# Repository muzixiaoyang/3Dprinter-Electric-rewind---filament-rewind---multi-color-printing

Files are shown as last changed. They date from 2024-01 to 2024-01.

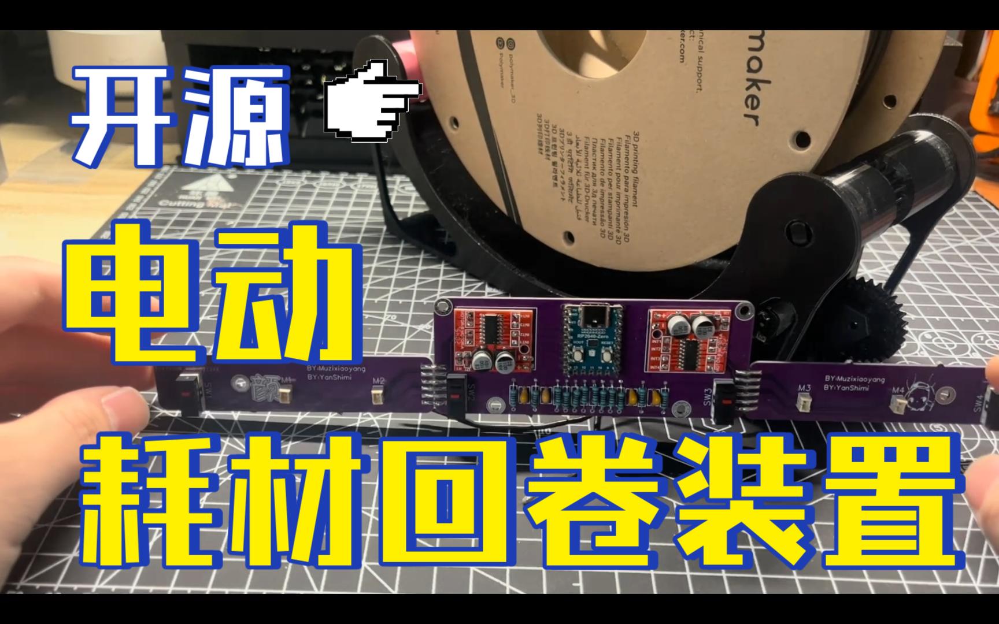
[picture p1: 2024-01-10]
封面.jpg

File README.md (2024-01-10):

# 3Dprinter-Electric-rewind---filament-rewind---multi-color-printing
【3D Printer】electric rewinf - filament rewind - multi-color printing
【3D打印机】稳定至上的电动回卷-耗材回卷-多色打印

During multi-color printing,
If you can't solve the winding in the rewind,
It will affect the next filament feeding and printing

The advantage of passive rewinding is that there is no involvement of electronic components.
However, there will be problems such as excessive resistance, complex structure, and large volume

So in the process of developing wood polychrome,
Specially designed for such as rabbit multicolor, TR multicolor, etc.,
Other types of multi-color printing are equipped with a motorized rewinding device
Advantages: cheap and quite cheap, simple structure, strong stability, long working time, long rewinding distance
Cons: Requires one or more USBs to be occupied

Thank you Yanshimi for your support and help
Thank you for the thoughts and ideas of the pending elder brother
Thanks to the group of friends Frog Brother copywriting and embellishment

在多色打印过程中，
如果不能解决回卷中缠绕，
将会影响下一次耗材的送料与打印

被动回卷的优势在于无电子元器件的参与，
但是会存在着阻力过大，结构复杂，体积较大的问题等

所以在开发木子多色的过程中，
特意为诸如兔子多色，TR多色等，
其他类别的多色打印预备了一套电动回卷装置
优势：价格便宜相当便宜，结构简单，稳定性强，工作时间长，回卷距离长
缺点：需要占用一个或多个USB

感谢Yanshimi大佬的支持与帮助
感谢群友待定老哥的思路与想法
感谢群友青蛙哥文案与修饰

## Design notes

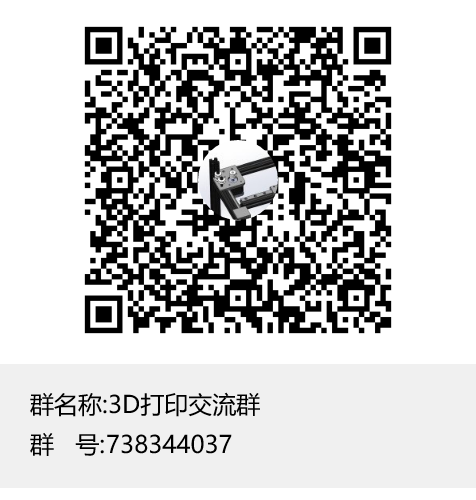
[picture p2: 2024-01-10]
【3D打印机】稳定之上的电动回卷-木子小阳/3D打印交流群群聊二维码.png

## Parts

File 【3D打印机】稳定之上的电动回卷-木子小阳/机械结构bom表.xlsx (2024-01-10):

本人仅提供材料链接，与店家并无任何利益关系 |  | 大家可以根据个人需求自行调整材料选取
B站演示链接： |  | https://www.bilibili.com/video/BV1MT4y1n7Rv/
嘉立创链接： |  | https://oshwhub.com/muzixiaoxiaoyang/dian-dong-hui-juan-mu-zi-xiao-yang
github链接： |  | https://github.com/muzixiaoyang/3Dprinter-Electric-rewind---filament-rewind---multi-color-printing
以后会出更多内容，可以关注一下不迷路
材料名称 | 材料数量 | 材料链接
608ZZ轴承 | 16 | https://item.taobao.com/item.htm?abbucket=13&id=559732852013&ns=1&skuId=3493880373151
鲍登头 | 4 | https://item.taobao.com/item.htm?id=654102804547&ns=1&abbucket=13
铜嵌入螺母【M3*4*5】 | 8 | https://detail.tmall.com/item.htm?_u=g2m84rkn86ac&id=691362839974&skuId=5085575338786
M1.6*4 | 8 | https://item.taobao.com/item.htm?id=732152088630&ns=1&abbucket=13
M3螺母 | 6 | https://item.taobao.com/item.htm?spm=a1z10.3-c-s.w4002-25176723813.11.188c504fscstHN&id=712768127528
M3*6螺丝 | 8 | https://item.taobao.com/item.htm?id=732152088630&ns=1&abbucket=13
M3*8螺丝 | 14 | https://item.taobao.com/item.htm?id=732152088630&ns=1&abbucket=13
M3*12螺丝 | 16 | https://item.taobao.com/item.htm?id=732152088630&ns=1&abbucket=13
M3*20螺丝 | 16 | https://item.taobao.com/item.htm?id=732152088630&ns=1&abbucket=13
此外不想组装或采购的话，可以直接咸鱼搜索”木子小阳“ | → | 那个卖干燥箱的就是我，我有这里有成品和套件售卖
 |  | B站：木子小小阳
 |  | QQ群：826091829

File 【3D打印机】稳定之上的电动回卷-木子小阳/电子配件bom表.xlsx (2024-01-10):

本人仅提供材料链接，与店家并无任何利益关系 |  | 大家可以根据个人需求自行调整材料选取
B站演示链接： |  | https://www.bilibili.com/video/BV1MT4y1n7Rv/
嘉立创链接： |  | https://oshwhub.com/muzixiaoxiaoyang/dian-dong-hui-juan-mu-zi-xiao-yang
github链接： |  | https://github.com/muzixiaoyang/3Dprinter-Electric-rewind---filament-rewind---multi-color-printing
以后会出更多内容，可以关注一下不迷路
材料名称 | 材料数量 | 材料链接
RP2040-Zero开发板 树莓派pico开发板 基于官方RP2040 焊排针 | 1 | https://item.taobao.com/item.htm?_u=72m84rkn8583&id=740532900376&spm=a1z09.2.0.0.2bac2e8dSXnIFg
2路直流电机驱动模块 正反转 | 2 | https://item.taobao.com/item.htm?spm=a1z09.2.0.0.2bac2e8dSXnIFg&id=576711157149&_u=72m84rkne464
金属膜电阻 1/4W 1% 五色环 10千欧 10K | 12 | https://item.taobao.com/item.htm?_u=72m84rkn68e4&id=522577576434&spm=a1z09.2.0.0.2bac2e8dSXnIFg
独石电容 0.1UF 104 100NF | 4 | https://item.taobao.com/item.htm?_u=72m84rkn4f11&id=522575085023&spm=a1z09.2.0.0.2bac2e8dSXnIFg1
1.25直针 1.25mm间距 2PIN | 4 | https://item.taobao.com/item.htm?id=528813512664&skuId=3148215795013
N20减速电机 | 4 | https://item.taobao.com/item.htm?_u=72m84rkn32a8&id=671009663139&spm=a1z09.2.0.0.7f3a2e8dZjZMkW
小型微动开关 无柄 （耗材检测款） | 4 | https://item.taobao.com/item.htm?id=607968305821&skuId=4441187151303
6MM钢珠（耗材检测款） | 4 | https://detail.tmall.com/item.htm?abbucket=13&id=620846633904&ns=1&skuId=4391174781008
此外不想组装或采购的话，可以直接咸鱼搜索”木子小阳“ | → | 那个卖干燥箱的就是我，我有这里有成品和套件售卖
 |  | B站：木子小小阳
 |  | QQ群：826091829

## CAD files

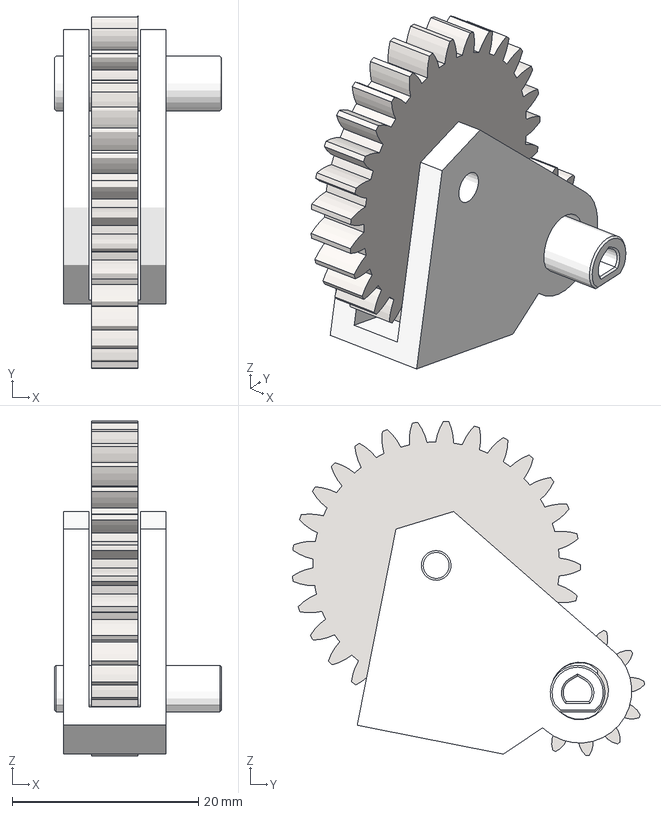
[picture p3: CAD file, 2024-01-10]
【3D打印机】稳定之上的电动回卷-木子小阳/打印件/20L款4通道电动回卷打印件-木子小阳/齿轮组4套.3mf
18.0 x 37.8 x 36.0 mm
实体1
实体2
实体3
实体4

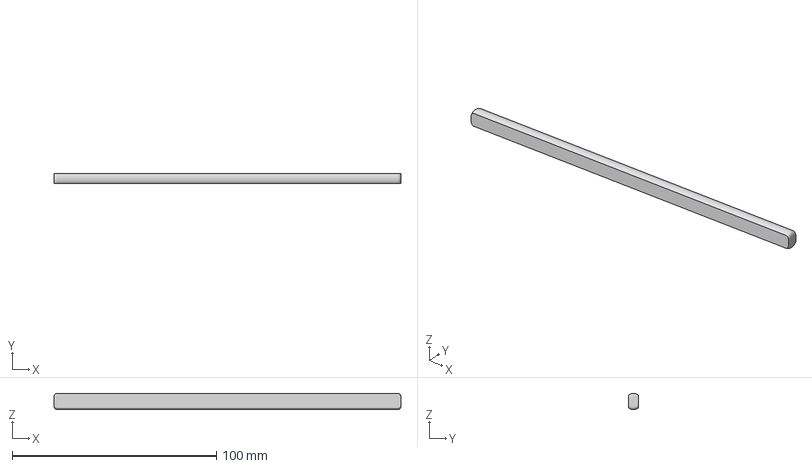
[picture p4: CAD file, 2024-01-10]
【3D打印机】稳定之上的电动回卷-木子小阳/打印件/4通道电动回卷耗材检测款-木子小阳/固定轴4套.3mf
170.0 x 5.00 x 8.00 mm

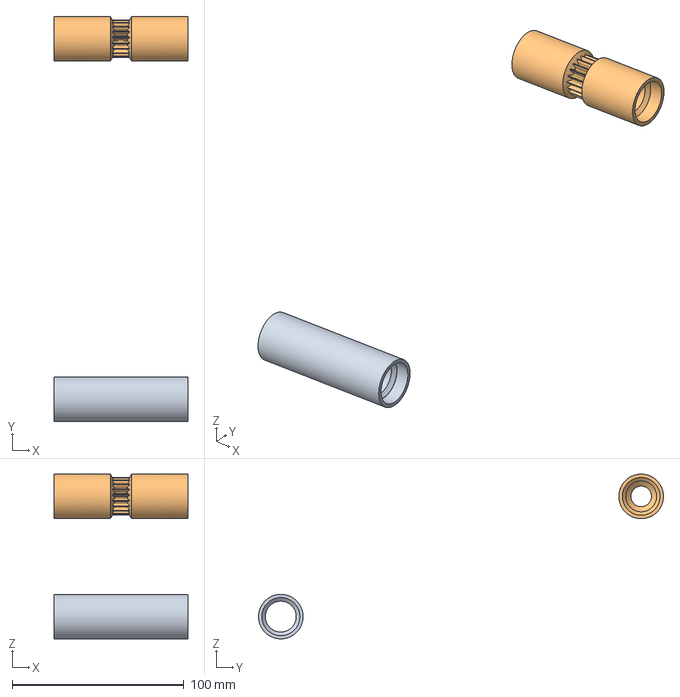
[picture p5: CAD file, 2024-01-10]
【3D打印机】稳定之上的电动回卷-木子小阳/打印件/20L款4通道电动回卷打印件-木子小阳/主动轴4套+被动轴4套.3mf
78.0 x 236.0 x 96.0 mm
实体1 x 2

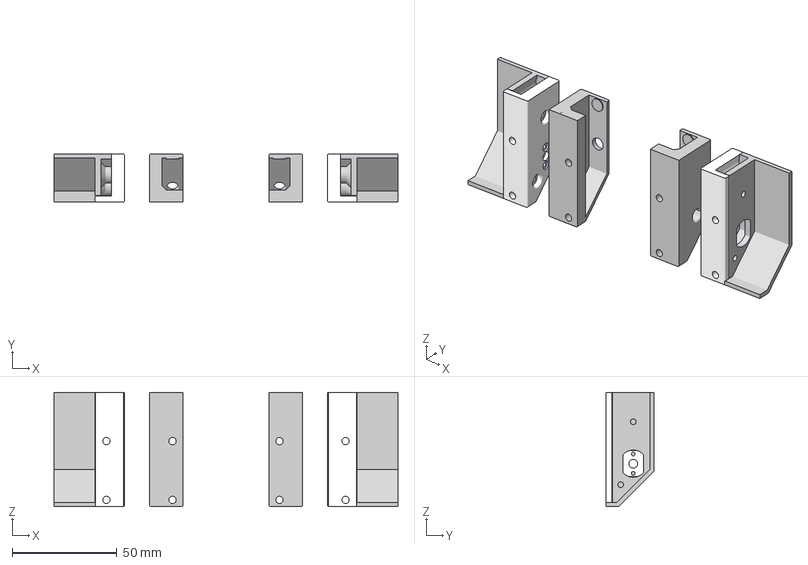
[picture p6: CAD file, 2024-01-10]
【3D打印机】稳定之上的电动回卷-木子小阳/打印件/4通道电动回卷耗材检测款-木子小阳/N20电机固定座2套.3mf
164.0 x 23.1 x 54.5 mm
实体1
实体2
实体3
实体4
实体5
实体6

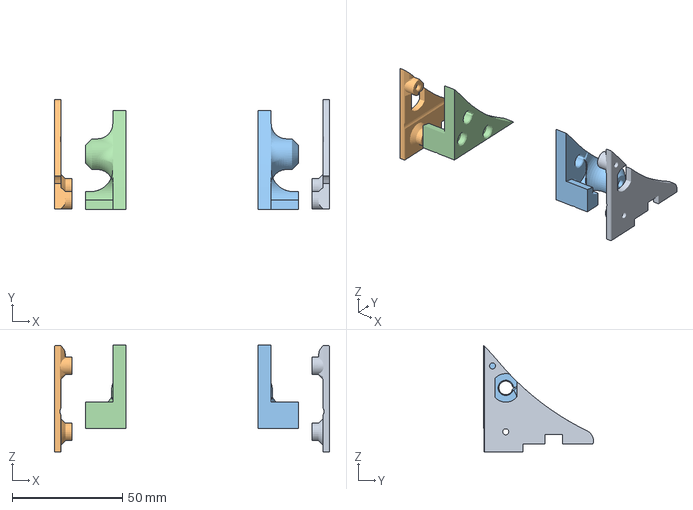
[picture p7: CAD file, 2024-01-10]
【3D打印机】稳定之上的电动回卷-木子小阳/打印件/20L款4通道电动回卷打印件-木子小阳/N20电机固定模组2套.3mf
125.0 x 50.0 x 48.5 mm
实体18 x 2
实体21 x 2

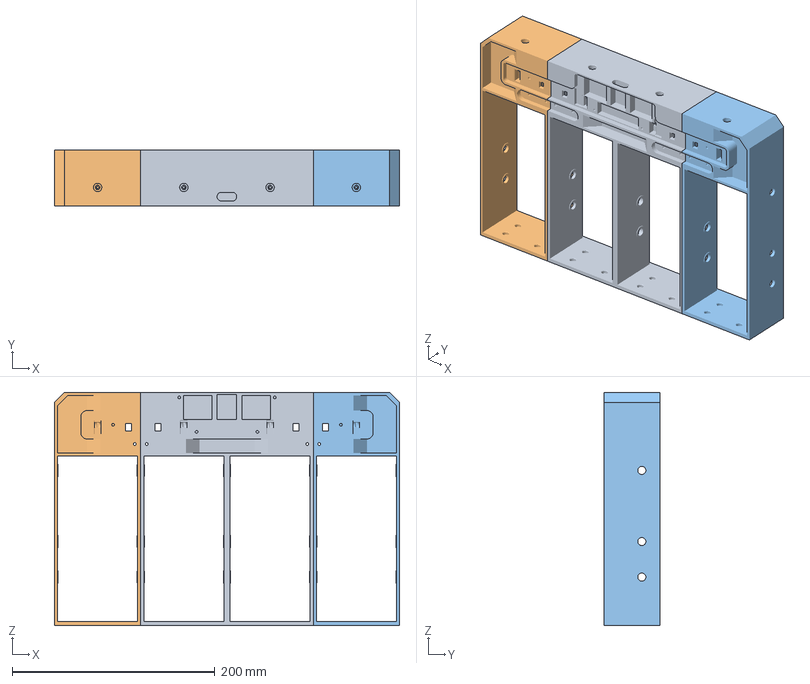
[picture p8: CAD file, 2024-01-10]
【3D打印机】稳定之上的电动回卷-木子小阳/打印件/4通道电动回卷耗材检测款-木子小阳/框架1套.3mf
340.0 x 55.4 x 230.0 mm
实体52
实体67
实体68

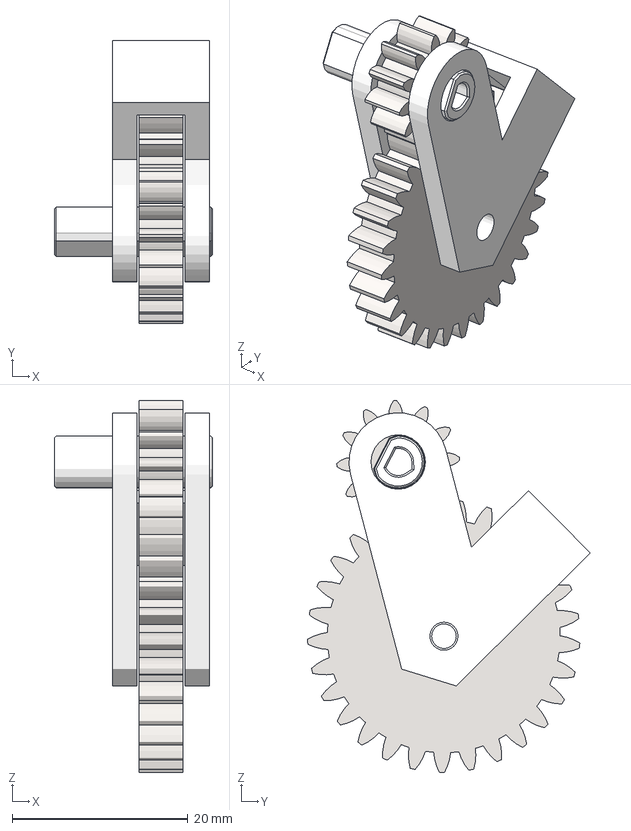
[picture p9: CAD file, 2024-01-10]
【3D打印机】稳定之上的电动回卷-木子小阳/打印件/4通道电动回卷耗材检测款-木子小阳/齿轮组4套.3mf
18.0 x 32.2 x 42.3 mm
实体1
实体2
实体3
实体4

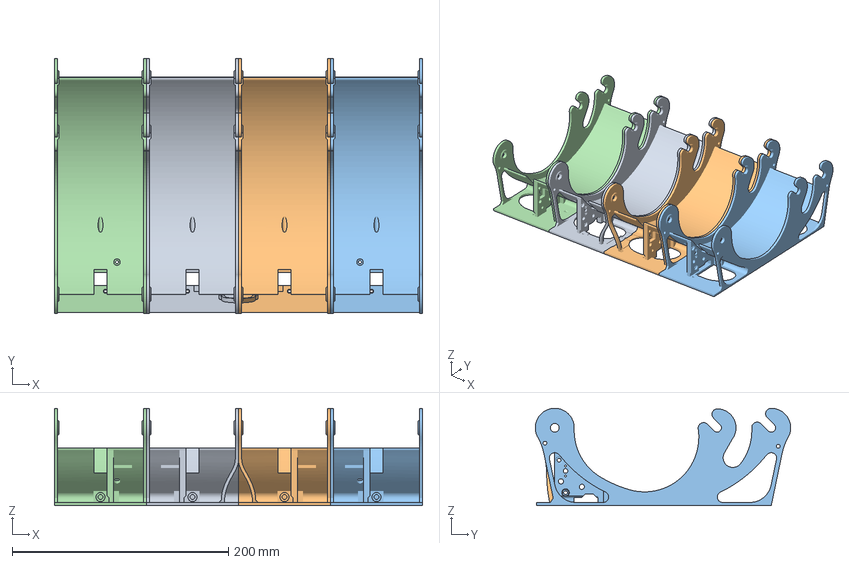
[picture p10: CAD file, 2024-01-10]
【3D打印机】稳定之上的电动回卷-木子小阳/打印件/20L款4通道电动回卷打印件-木子小阳/4通道电动回卷固定底座1套4组.3mf
340.0 x 236.0 x 90.0 mm
实体46
实体51
实体54
实体55

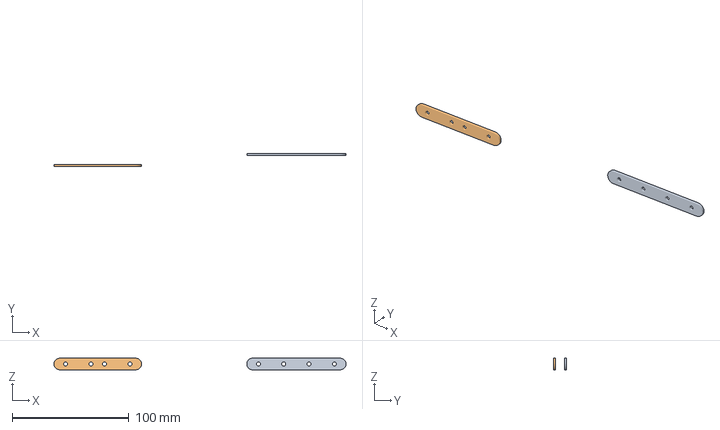
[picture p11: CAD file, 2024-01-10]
【3D打印机】稳定之上的电动回卷-木子小阳/打印件/4通道电动回卷耗材检测款-木子小阳/连接横杆.3mf
249.9 x 11.4 x 10.0 mm
实体29
实体30

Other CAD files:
【3D打印机】稳定之上的电动回卷-木子小阳/打印件/20L款4通道电动回卷打印件-木子小阳/通轴4套.3mf
【3D打印机】稳定之上的电动回卷-木子小阳/打印件/4通道电动回卷耗材检测款-木子小阳/主动轴4套+被动轴4套.3mf

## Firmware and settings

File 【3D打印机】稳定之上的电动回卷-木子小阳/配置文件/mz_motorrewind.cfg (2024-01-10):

[mcu c1]
serial:/dev/serial/by-id/usb-Klipper_rp2040_E6625887D375A032-if00
#serial:/dev/serial/by-id/usb-Klipper_rp2040_E6625887D3458330-if00


[filament_switch_sensor A-INPUT]
switch_pin:c1:gpio14
[filament_switch_sensor B-INPUT]
switch_pin:c1:gpio15

[filament_switch_sensor C-INPUT]
switch_pin:c1:gpio7
[filament_switch_sensor D-INPUT]
switch_pin:c1:gpio8


[output_pin re_3]
pin:c1:gpio26
value:0
# pwm: 1
# cycle_time: 0.100

[output_pin un_3]
pin:c1:gpio27
value:0


[output_pin un_2]
pin:c1:gpio28
value:0
# pwm: 1
# cycle_time: 0.100

[output_pin re_2]
pin:c1:gpio29
value:0


[output_pin re_1]
pin:c1:gpio3
value:0
# pwm: 1
# cycle_time: 0.100

[output_pin un_1]
pin:c1:gpio4
value:0


[output_pin un_0]
pin:c1:gpio5
value:0
# pwm: 1
# cycle_time: 0.100

[output_pin re_0]
pin:c1:gpio6
value:0



[gcode_macro COLORS_REWIND_VAR]
description: 保存耗材回卷相关变量的空宏

#变量数组的创建【不要改】
variable_now_filament: -1        #feiw 当前需要回卷过的耗材色号，开机时默认没有（-1值）
#通过【SET_GCODE_VARIABLE MACRO=<macro_name> VARIABLE=<name> VALUE=<value>】修改，例:SET_GCODE_VARIABLE MACRO=COLORS_VAR VARIABLE=Thaoma VALUE=1
                               
gcode:


[gcode_macro rewind]   #feiw 回卷指定耗材【添加到换色退料宏中 步进电机开始回卷前的一行】
description: 回卷指定耗材
gcode:
  {% set COLORS_REWIND_VAR = printer["gcode_macro COLORS_REWIND_VAR"] %}
  {% set Current_T = params.CURRENT_FILAMENT|int %}            # 引用虚拟外部变量(指定需要回卷的耗材号)

  SAVE_GCODE_STATE NAME=rewind # 保存当前g代码坐标解析状态，便于进行Gcode编辑后恢复状态

  SET_PIN PIN=re_{Current_T} VALUE=1

  SET_GCODE_VARIABLE MACRO=COLORS_REWIND_VAR VARIABLE=now_filament VALUE={Current_T}  # 修改耗材色号为 【params.CURRENT_FILAMENT】
  RESTORE_GCODE_STATE NAME=rewind MOVE=1 MOVE_SPEED=100   # 恢复当前g代码坐标解析状态

[gcode_macro unrewind]   #feiw 关闭回卷【添加到换色退料宏中 步进电机启动行后面的下一行（注：若原回卷宏中 全部结束阶段没有M400,需要再本宏名称的上一行添加M400）】
description: 关闭回卷
gcode:
  {% set COLORS_REWIND_VAR = printer["gcode_macro COLORS_REWIND_VAR"] %}
  {% set now_filament = COLORS_REWIND_VAR.now_filament|int %}             #feiw 读取参数库中当前耗材值
  {% set Current_T = params.CURRENT_FILAMENT|default(now_filament)|int %} #feiw 传参 断电时候的耗材的序号 “0、1、2、3”
  
   SAVE_GCODE_STATE NAME=unrewind      # 保存当前g代码坐标解析状态，便于进行Gcode编辑后恢复状态
  # 开始卷料
   SET_PIN PIN=re_{Current_T} VALUE=0
   SET_PIN PIN=un_{Current_T} VALUE=1
    G4 P2000                                           # 驻留：G4 P<毫秒> 【脱离齿轮关联】
   SET_PIN PIN=un_{Current_T} VALUE=0

   RESTORE_GCODE_STATE NAME=unrewind MOVE=1 MOVE_SPEED=100

[gcode_macro moverewind]
description: 初始化所有电动回卷
gcode:
   SAVE_GCODE_STATE NAME=moverewind # 保存当前g代码坐标解析状态，便于进行Gcode编辑后恢复状态
  # 开始卷料
   SET_PIN PIN=re_0 VALUE=0
   SET_PIN PIN=re_1 VALUE=0
   SET_PIN PIN=re_2 VALUE=0
   SET_PIN PIN=re_3 VALUE=0
    G4 P1000                                           # 驻留：G4 P<毫秒> 【脱离齿轮关联】
   SET_PIN PIN=un_0 VALUE=1
   SET_PIN PIN=un_1 VALUE=1
   SET_PIN PIN=un_2 VALUE=1
   SET_PIN PIN=un_3 VALUE=1
    G4 P2000                                           # 驻留：G4 P<毫秒> 【脱离齿轮关联】
    SET_PIN PIN=un_0 VALUE=0
    SET_PIN PIN=un_1 VALUE=0
    SET_PIN PIN=un_2 VALUE=0
    SET_PIN PIN=un_3 VALUE=0

   RESTORE_GCODE_STATE NAME=moverewind MOVE=1 MOVE_SPEED=100   # 恢复当前g代码坐标解析状态
